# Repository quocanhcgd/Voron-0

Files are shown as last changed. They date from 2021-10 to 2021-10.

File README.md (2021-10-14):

# Voron Zero

Image of Voron Zero

The official release of the Voron Zero 3d printer.  You can find the BOM in the configurator located at the [Voron Design]( http://vorondesign.com/voron0) website.

The current revision is V0.1.

## Highlights
- Compact and portable
- 120x120x120 build volume
- CoreXY
- Low mass direct drive extruder
- Enclosed chamber
- 24v DC bed simplifies electronics
- Klipper firmware

## Release History
### V0.1 (2021 April)

A majority of the printed parts have changed. The configurator will give you an idea of parts needed if you are upgrading from V0.0.

**Toolhead**
- New design: Mini Afterburner
- Direct Drive Extruder with BMG gears and pancake motor with 10 tooth spur gear
- Improved part cooling ducts (fans are same as V0.0)
- Supports Mosquitto, Dragon, Dragonfly mounts
- V6 mount too large for DDE (bowden still an option)

**Z motor**
- Simplified to use Nema17 integrated T8x8 200mm leadscrew and printed mount (highly recommended upgrade)

**Drive units**
- A/B steppers changed to larger 40Ncm motors for increased torque (optional upgrade)
- Parts are now embossed with “A” or “B” respectively to avoid improper assembly
- Motor screws are countersunk to add more thread engagement 
- Panel mount point added

**Frame**
- No changes

**Electronics**
- Move from AC to 24v 60 watt DC bed (no more SSR)
- 150 watt PSU (larger to support DC bed)
- Fused AC power inlet (now with switch)
- SKR moves to rear compartment and Mini E3 V2.0 now spec
- PSU terminal cover

**Tophat**
- All panels have changed
- Front and rear are now straight vertical to accommodate new toolhead
- Sides went from 15° to 10°
- 10mm taller all around
- Lower panel clips are built into frame mounts

**Panels/clips**
- Front deck panel is unchanged
- Mid and back panel has various holes removed (can use your V0.0 panels)
- Rear deck panel is gone
- Motor panel is added (can be printed later)
- Side windows and door are unchanged
- Rear upper panel clips have an added mount point

**X/Y Joints**
- Hex nuts replaced with threaded inserts
- Idlers replaced by F623 bearing stack (hole adjusted to align perfectly in CAD)
- Endstop block changed to be compatible with DD toolhead
- Inaccessible bottom gantry screw holes removed

**Bed Assembly**
- Rear mounts extended 3mm to account for DD toolhead position changes
- Z chain mount adjusted to accommodate off-the-shelf chain or printed beltchain
- Zip tie mounts added for cable routing
- Removed horizontal bolt hole to prevent over-constraining assembly 
- Front mount reduced in size for less plastic use
- Printed thumb screws for bed adjustments

**Feet/Skirts**
- Extended to accommodate 34mm Z motor

**Front Idlers**
- No changes

### V0.0 Updates and fixes (2020 Sept)
See https://github.com/VoronDesign/Voron-0/releases/tag/V0.0r1

### V0.0 Initial release (2020 April)
See https://github.com/VoronDesign/Voron-0/releases/tag/V0.0

Voron Logo

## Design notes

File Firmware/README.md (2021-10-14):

# Voron 0.1 Stock Printer Config Example

For detailed instructions on setting up your Voron, visit
https://docs.vorondesign.com/build/startup/

As always, check Discord #voron_0_questions for help

## Quick Start
* Find and update your unique mcu `serial`
* Do a `STEPPER_BUZZ STEPPER=stepper_x` and repeat for each stepper
* Test each endstop using `QUERY_ENDSTOPS`
* Be ready to emergency stop, practice it
* Try homeing each axis, `G28 X` then `G28 X Y` then `G28`
* Adjust direction `dir_pin` as necessary
* Do a `BED_SCREWS_ADJUST` with the paper test
* Check fans are working properly
* Validate your thermistors `sensor_type`
* Tune bed `PID_CALIBRATE HEATER=heater_bed TARGET=100`
* Tune hotend with `M106 S64` then `PID_CALIBRATE HEATER=extruder TARGET=245`

## Warnings
* If using mainsail or others, you will likely need a special include or other adjustments
* You may need to swap your A/B motor physical connections and/or software stepper directions
* This firmware assumes stock BOM with Mini Afterburner DD toolhead

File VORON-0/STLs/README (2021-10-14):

STL's for RC1 release of VORON Zero

Files that are Prefixed with [a]_ are intended to be printed in the accent color all other files are intended to be printed in the base color

toolhead folders contain all the parts that need to be printed for each specific toolhead, print the parts that match the hotend you are using.

Panel mounting clips are offered in 3 sizes. print the sizes that matches the thickness of the panels you are using.

The TopHat is available in a unibody one piece design as well as a 4 piece design (for printing directly on the V0) choose one or the other, 
you do not need both. the mounting brackets for tophat panels are also offered in 3 sizes. print the sizes that matches the thickness of the panels you are using.

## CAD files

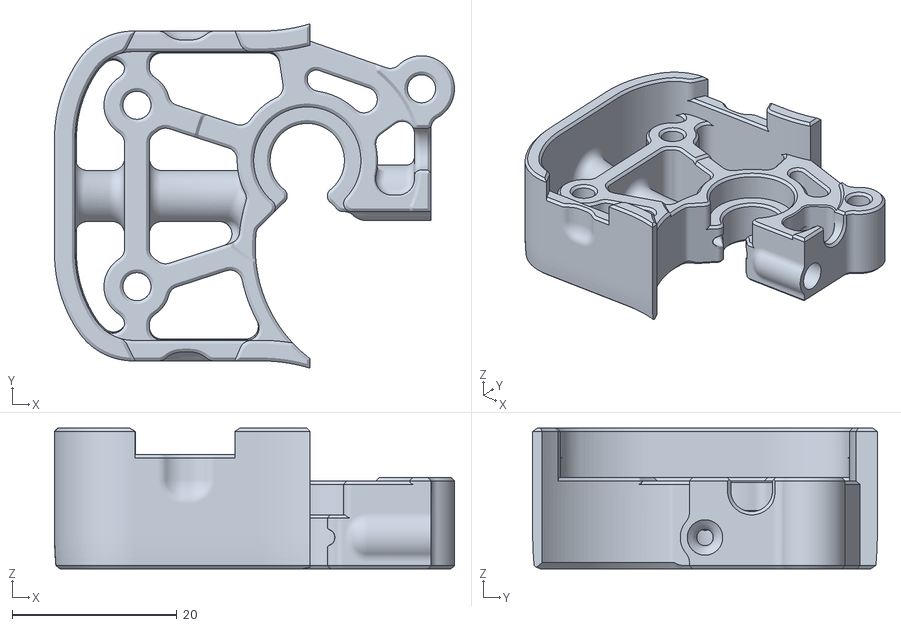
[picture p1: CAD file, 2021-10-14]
STLs/Toolheads/Mini_Afterburner/Dragon_Toolhead_DD/[a]_Mid_Body_Dragon_x1.stl
48.5 x 41.8 x 17.0

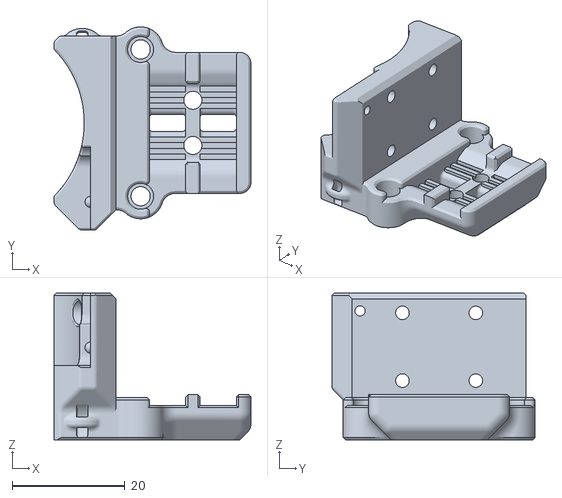
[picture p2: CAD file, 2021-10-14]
STLs/Toolheads/Mini_Afterburner/X_Carriage_90_x1.STL
34.9 x 36.0 x 26.0

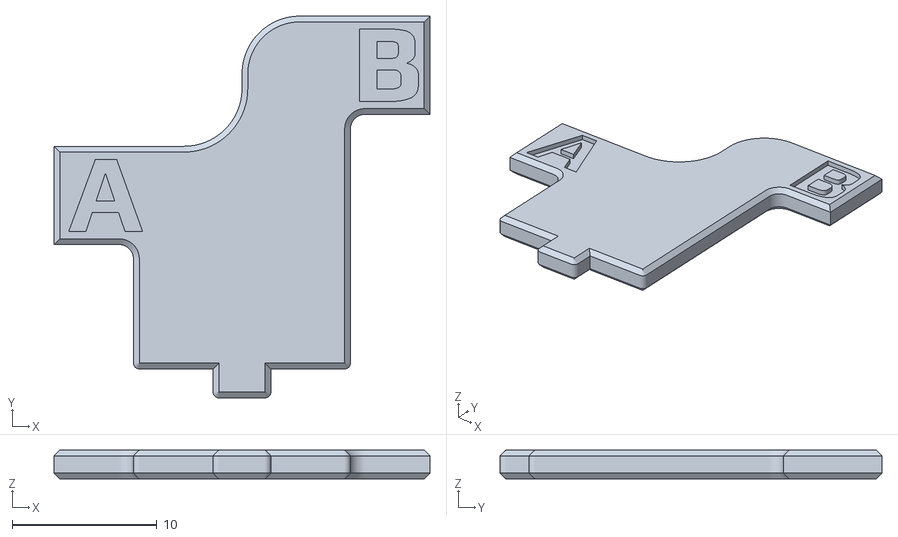
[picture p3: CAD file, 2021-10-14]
STLs/Tools/AB_pulley_jig_x1.stl
26.0 x 26.4 x 2.00

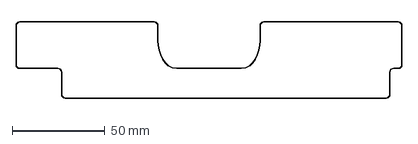
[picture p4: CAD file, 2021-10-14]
VORON-0/DXFs/Deck_Panel_Rear_V0.DXF
208.0 x 41.0 mm

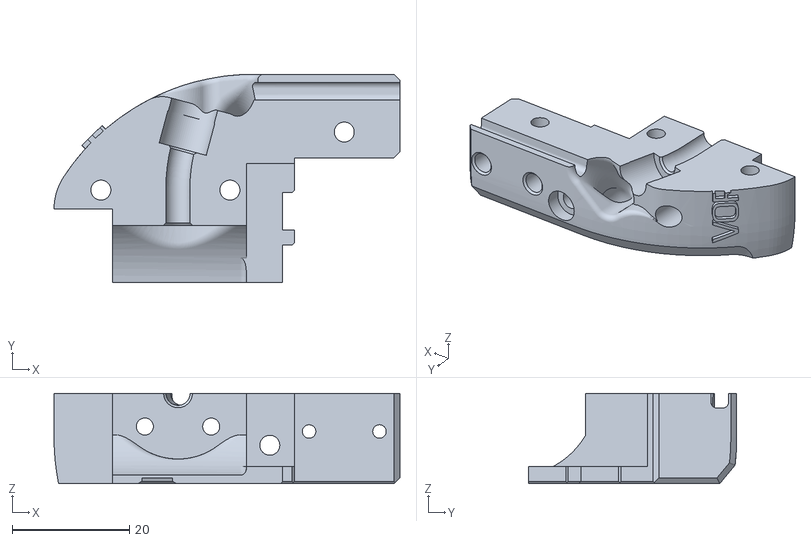
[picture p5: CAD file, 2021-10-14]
VORON-0/STLs/Dragon_Toolhead/Toolhead_Left_Dragon_x1.STL
59.0 x 35.6 x 15.4

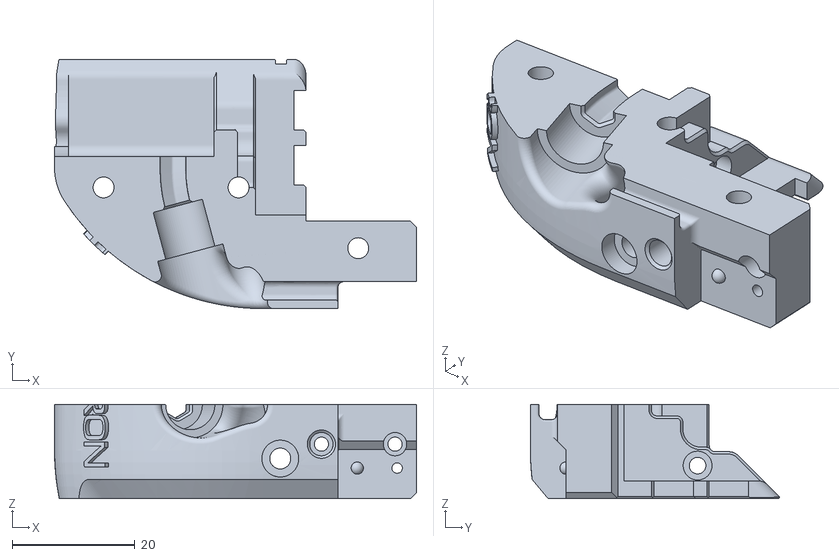
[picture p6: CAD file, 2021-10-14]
VORON-0/STLs/Mosquito_Toolhead/Toolhead_Right_Mosquito_x1.STL
59.0 x 40.6 x 15.4

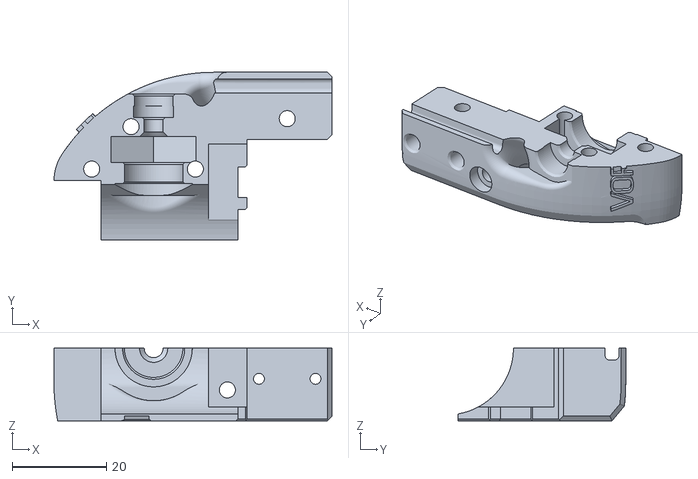
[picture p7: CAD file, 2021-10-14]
VORON-0/STLs/Threaded_V6_Toolhead/Toolhead_Left_Threaded_V6_x1.STL
59.0 x 35.6 x 15.4

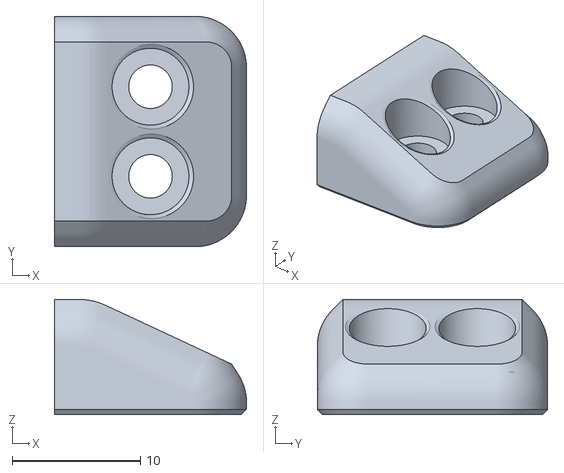
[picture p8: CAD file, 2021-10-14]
VORON-0/STLs/V0_Panel_Mounting/Door_Latch_x2.STL
15.0 x 18.0 x 9.00

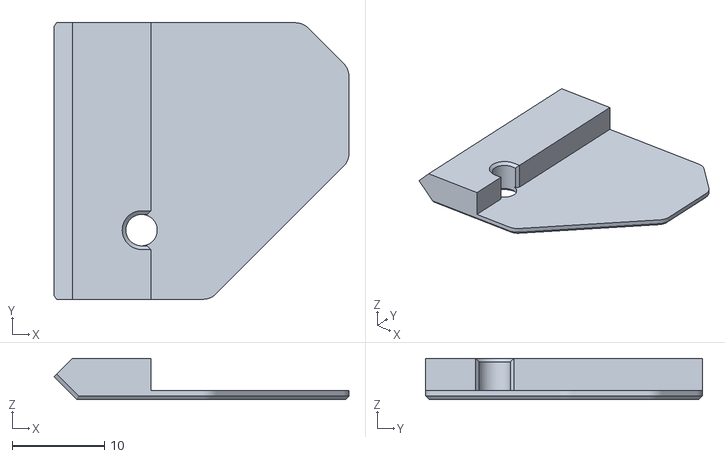
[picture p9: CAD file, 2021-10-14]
VORON-0/STLs/V0_Panel_Mounting/For_2.5mm_Panels/2point5mm_Bottom_Corner_Rear_x1.STL
32.0 x 30.0 x 4.50

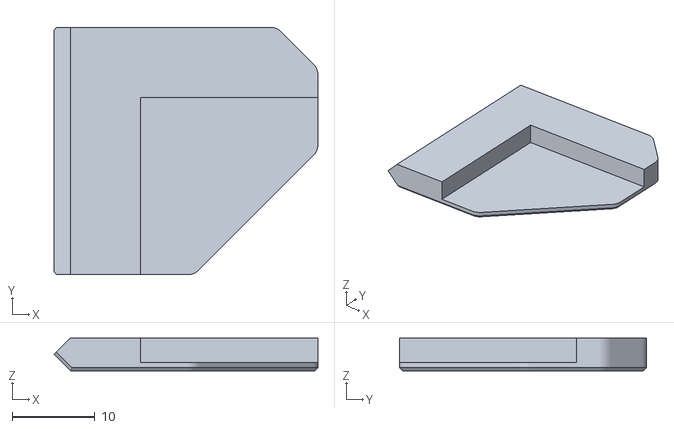
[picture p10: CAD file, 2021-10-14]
VORON-0/STLs/V0_Panel_Mounting/For_2mm_Panels/2mm_Bottom_Corner_Front_x1.STL
32.0 x 30.0 x 4.00

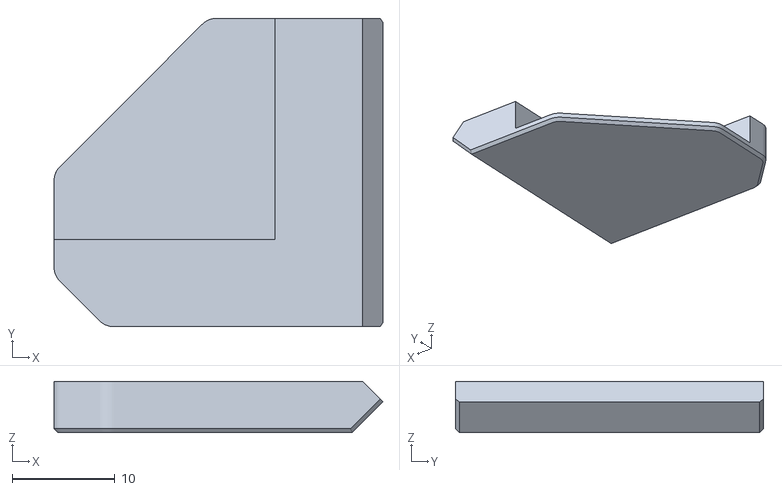
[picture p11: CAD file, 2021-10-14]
VORON-0/STLs/V0_Panel_Mounting/For_3mm_Panels/3mm_Bottom_Corner_Front_x1.stl
32.0 x 30.0 x 5.00

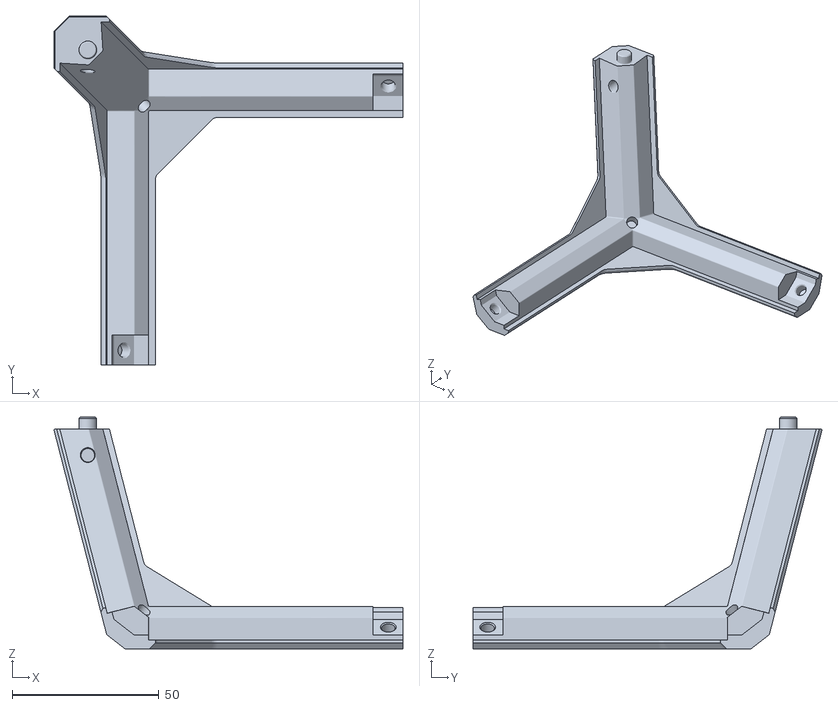
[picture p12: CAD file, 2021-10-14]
VORON-0/STLs/V0_TopHat/4_Piece_Tophat/TopHat_Right_x2.STL
119.0 x 119.0 x 79.0

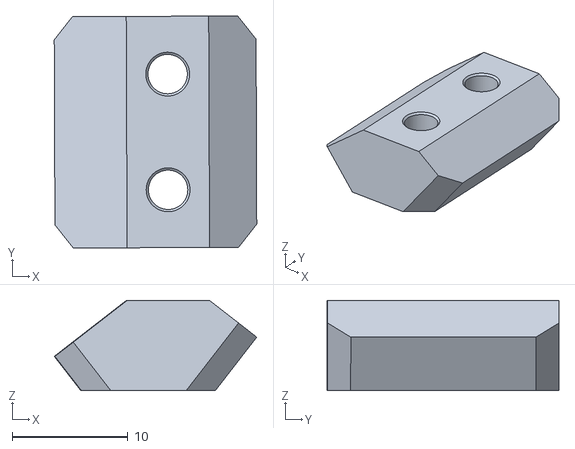
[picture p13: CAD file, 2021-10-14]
VORON-0/STLs/V0_TopHat/TopHat_Panel_Mounting/For_2.5mm_Panels/2point5mm_TH_Mid_Clip_x4.STL
17.5 x 20.1 x 7.78

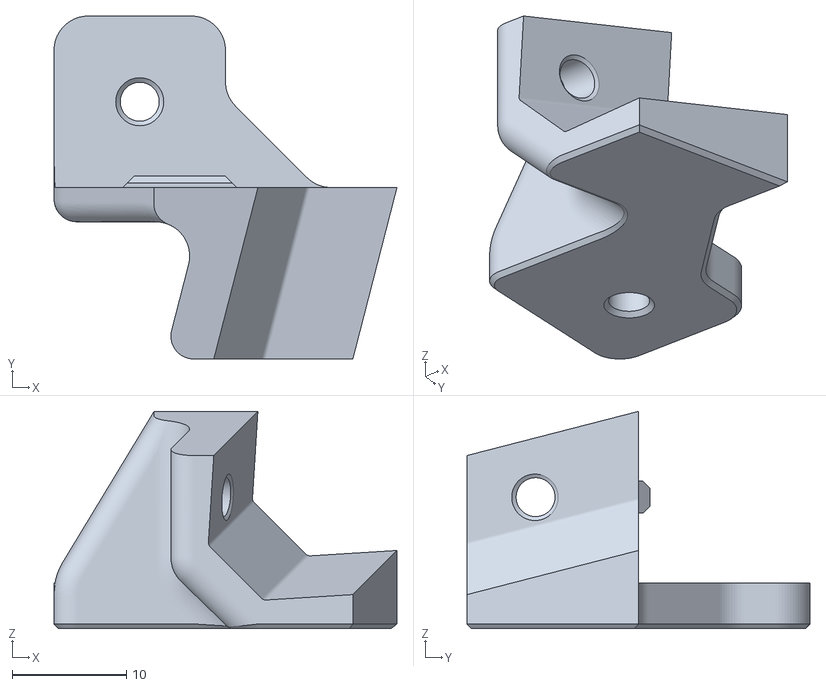
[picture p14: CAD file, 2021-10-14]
VORON-0/STLs/V0_TopHat/TopHat_Panel_Mounting/For_2mm_Panels/2mm_TH_Lower_Corner_Clip_Right_x2.stl
30.0 x 30.0 x 19.0

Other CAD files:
VORON-0/STLs/V0_TopHat/TopHat_Panel_Mounting/For_3mm_Panels/3mm_TH_Lower_Corner_Clip_Right_x2.stl
VORON-0/STLs/V0_TopHat/Unibody_Tophat/Unibody_Tophat_x1.STL
VORON_Pocketwatch/STLs/[a]_Mount_Bracket_x1.STL
VORON-0/DXFs/Back_Panel_V0.DXF
VORON-0/DXFs/Deck_Panel_V0.DXF
VORON-0/DXFs/Mid_Panel_V0.DXF
VORON-0/DXFs/TopHat_Side_Panel.DXF
VORON-0/STLs/A_Drive_Frame_Bottom_x1.STL
VORON-0/STLs/A_Drive_Frame_Top_x1.STL
VORON-0/STLs/A_Idler_Bottom_x1.STL
VORON-0/STLs/A_Idler_Top_x1.STL
VORON-0/STLs/B_Drive_Frame_Bottom_x1.STL
VORON-0/STLs/B_Drive_Frame_Top_x1.STL
VORON-0/STLs/B_Idler_Bottom_x1.STL
VORON-0/STLs/B_Idler_Top_x1.STL
VORON-0/STLs/Dragon_Toolhead/Toolhead_Right_Dragon_x1.STL
VORON-0/STLs/Front_Bed_Mount_x1.STL
VORON-0/STLs/M2_Nut_Adapter_Rotated_x5.stl
VORON-0/STLs/MGN7_Rail_Guide_x2.STL
VORON-0/STLs/RPi_Frame_x1.stl
VORON-0/STLs/Skirt_mirror_x3.STL
VORON-0/STLs/Skirt_x3.STL
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

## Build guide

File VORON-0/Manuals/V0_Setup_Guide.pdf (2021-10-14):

# Voron Design SKR Mini E3 Setup Guide

V0.0

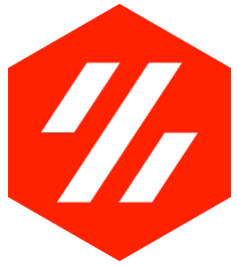
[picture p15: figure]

# Power Supply Wiring

## Safety Note

When wiring up your printer electronics, you will be working with high voltage wiring. Always double check to make sure that the printer is unplugged and any capacitors in your power supplies have discharged before touching any wire or terminal that may be live.

## Damage Risk

Never plug or unplug any device (high or low voltage) while the the printer is powered. In addition to being a safety hazard, you will likely damage electronic components. Of particular note are stepper drivers which can easily be damaged by connecting or disconnecting stepper motors or drivers while powered.

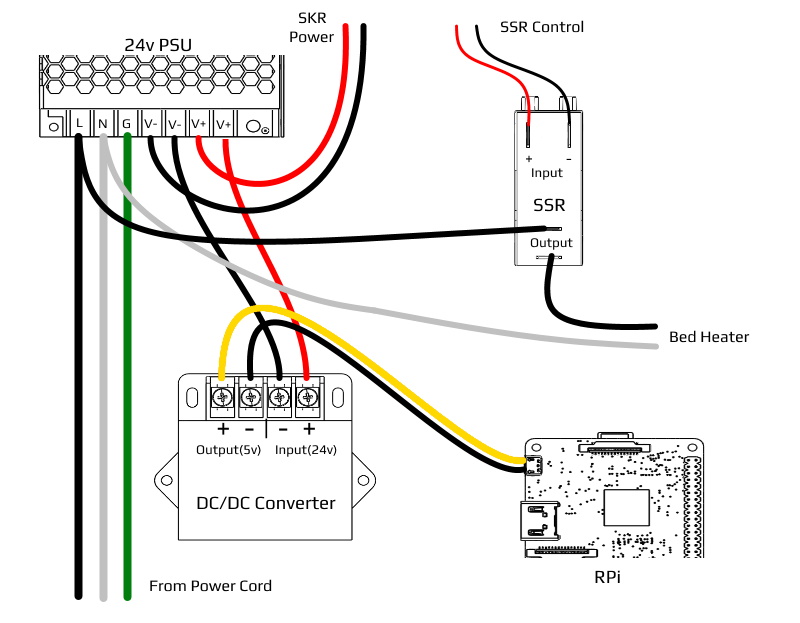
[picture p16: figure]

# SKR E3 Board Configuration

## Jumper Configuration

- Make sure power jumper is between INT and +5V (should be default from factory). If this is not installed correctly you may have power issues with your Raspberry Pi which can cause throttling

## Wire Terminals

SKR E3 boards use JST-XH terminals. This will mean that you will need to purchase a JST-XH connector kit with 2 pin, 3 pin, and 4 pin connectors. JST-XH terminals are keyed and will only fit in one orientation so pay close attention while crimping to make sure you do not make a mistake. You can carefully de-pin connectors with a dental pick, toothpick, or similar.

For wiring the stepper motors, keep the same wire color sequence that your stepper motors came with and make sure you use the same sequence for all of your stepper motors. If you have the spec motors from StepperOnline, the wires should in the the color order shown in the SKR E3 wiring diagrams on the following pages.

Note: Steppers should ship with a diagram that outlines wire pairs. You can also determine pairs by touching two wires together. If the stepper becomes more difficult to turn, then you have found a pair. These methods can be used if your wire colors are different or you mislabel wire order.

Important: If you find out your motors are going the wrong way once you start up your printer for the first time, you do not need to repin your connectors. You can invert the DIR (direction) pins in your configuration by adding or removing ! in front of pin and it will work properly.

## Endstop Wiring

There are two ways of wiring your endstops, one is NC (normally closed) and the other is NO (normally open). For normally closed configurations, the endstop switch allows current to flow through it when it is not triggered. For normally open configurations, the end stop switch only allows current to flow through it when it is triggered.

While both of these configurations will work fine in an ideal world, NC configurations are more robust because if a wire breaks or a terminal becomes disconnected, the printer will think that the end stop has triggered and the printer will stop movement before the toolhead crashes in to the frame or the bed.

Wiring mechanical end stop switches for NC operation is easy, as they generally have three pins exposed. With a multimeter, probe each combination of the three pins until you find a pair that has continuity (0 ohm resistance) when the switch is not triggered,

## MCU Wiring (X, Y, E, Hot End)

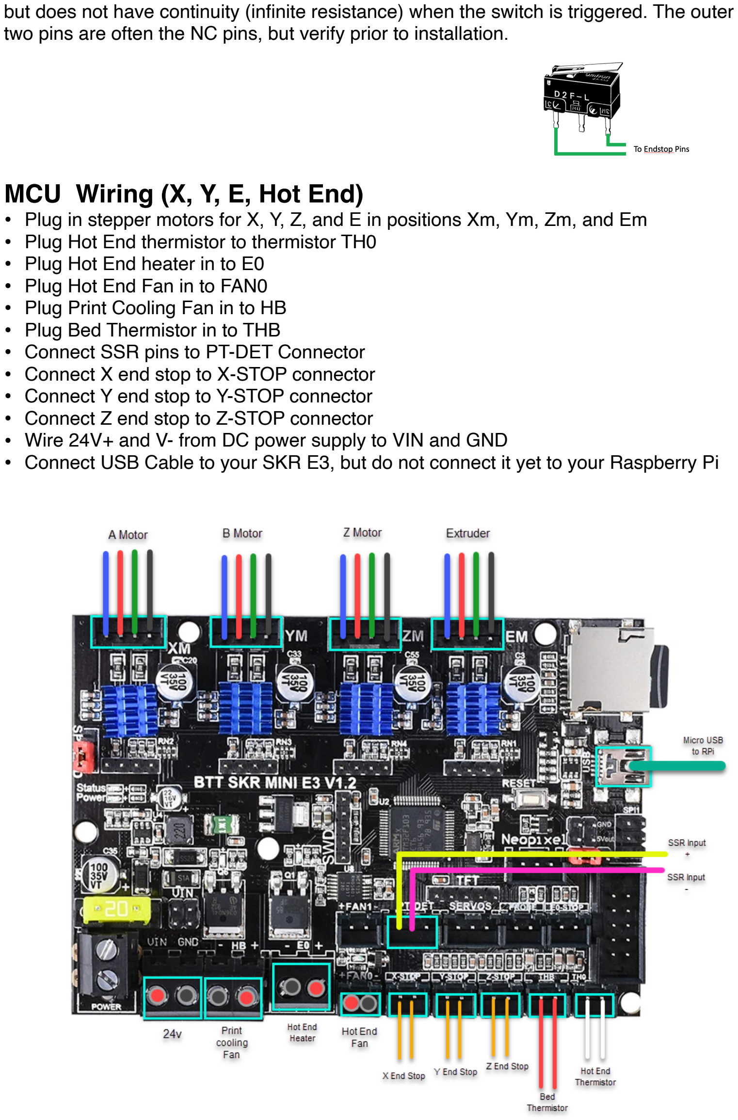
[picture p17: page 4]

but does not have continuity (infinite resistance) when the switch is triggered. The outer two pins are often the NC pins, but verify prior to installation.

- Plug in stepper motors for X, Y, Z, and E in positions Xm, Ym, Zm, and Em
- Plug Hot End thermistor to thermistor TH0
- Plug Hot End heater in to E0
- Plug Hot End Fan in to FAN0
- Plug Print Cooling Fan in to HB
- Plug Bed Thermistor in to THB
- Connect SSR pins to PT-DET Connector
- Connect X end stop to X-STOP connector
- Connect Y end stop to Y-STOP connector
- Connect Z end stop to Z-STOP connector
- Wire 24V+ and V- from DC power supply to VIN and GND
- Connect USB Cable to your SKR E3, but do not connect it yet to your Raspberry Pi

# Klipper Installation

References: Klipper Installation Instructions SKR Installation Instructions

## Installing Klipper Firmware on your SKR Mini E3 Board

- Install OctoPi on your Raspberry Pi (guide here: https://octoprint.org/download/)
- Once it is installed, ssh in to your Raspberry Pi using PuTTY on Windows or the Terminal on macOS

ssh pi@octopi OR ssh pi@192.168.1.X (Or whatever ip address your Raspberry Pi has)

- Enter password, the default one is “raspberry”. It is recommended to change this for security using
sudo raspi-config
Change the password via “Change User Password”
- Once you are at the command line of the Raspberry Pi, run the following commands: git clone https://github.com/KevinOConnor/klipper./klipper/scripts/install-octopi.sh
- When the install script has completed, run the following commands:
cd ~/klipper/
make menuconfig

In this menu structure, you’ll want to pick a few things. Make sure your Micro-controller Architecture is STM32, and your processor model is the STM32F103 with a 28KiB bootloader. Also select "enable extra low-level configuration options" and configure "GPIO pins to set at micro-controller startup" to "!PC13".
When your configuration matches the image below, select Exit and “Yes” if you are asked to save the configuration.

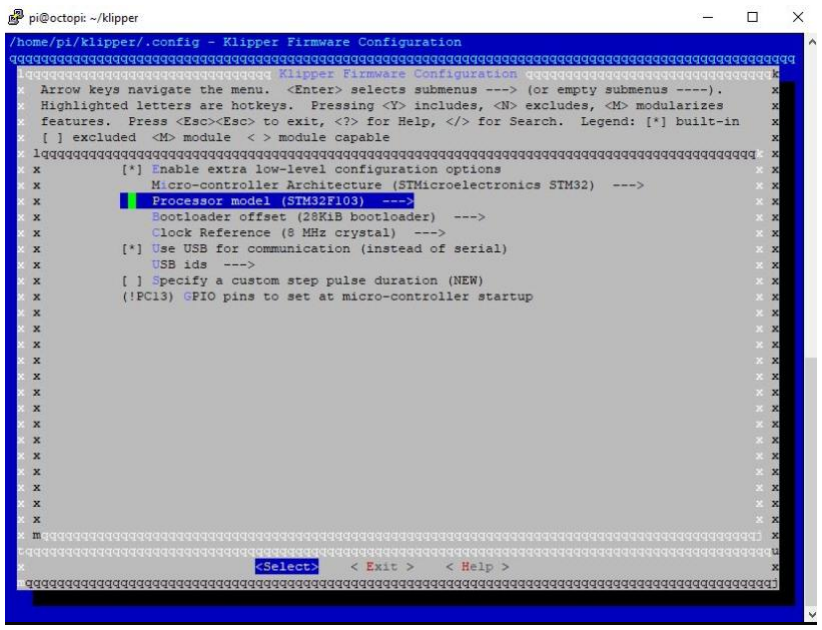
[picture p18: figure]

In the terminal window, type the following and pressing enter after each:

make clean

make

This command creates a firmware file klipper.bin that is stored in the folder /home/pi/ klipper/out.
The file needs to be copied to your Mini E3 board. The easiest way to do this is to use a program like WinSCP (Windows) or Cyberduck (Mac) to copy the file to your computer via SFTP. See the image on the next page that shows SFTP via Cyberduck.
- Copy the klipper.bin file to your desktop, and rename the file firmware.bin

Make sure the SKR Mini E3 is not powered, and then remove the microSD card.

- Connect the microSD card to your computer and open it.

There will be a file named firmware.cur on it—you can delete that file or keep it there, it does not matter.

- Copy the firmware.bin file from your desktop to the microSD card. If you have trouble transferring files from your computer to the microSD card, reformat the microSD card with a FAT32 file system and then try again.
- Plug the microSD cards back in to your SKR E3 board
- Turn on your power supply to power up your SKR E3 boards

Important: If you do not power your SKR with 12-24V, Klipper will be unable to communicate with the TMC drivers via UART and it will automatically shut down.

## Configuring Octoprint to use Klipper

Reference: KevinOConnor - klipper/docs/Installation.md
The OctoPrint web server needs to be configured to communicate with the Klipper host software.

Using a web browser, login to the OctoPrint web page and then configure the following items:

- Navigate to the Settings tab (the wrench icon at the top of the page)
- Under "Serial Connection" in "Additional serial ports" add "/tmp/printer" then click "Save"
- Open Settings tab and under "Serial Connection" change the "Serial Port" setting to "/ tmp/printer"
- In the Settings tab, navigate to the "Behavior" sub-tab and select the "Cancel any ongoing prints but stay connected to the printer" option, then click “Save”
- From the main page, under the "Connection" section (at the top left of the page) make sure the "Serial Port" is set to "/tmp/printer" and click "Connect". (If "/tmp/ printer" is not an available selection then try reloading the page)
- Once connected, navigate to the "Terminal" tab and type "status" (without the quotes) into the command entry box and click "Send". The terminal window will likely report there is an error opening the config file - that means OctoPrint is successfully communicating with Klipper.

## Setting up Voron Printer Configuration File

- Download the Voron Zero configuration file from the VORON 0 Github
- Transfer the downloaded file to your raspberry pi in the following folder: ~/home/pi

Note: There are many ways of editing your config file. Using the built-in Nano editor through SSH is simple, but it is not user friendly. Notepad++ with the NppFTP plugin (Windows) or bbEdit (MacOS) are better alternatives. Instructions on how to use them are in the appendix.

- Review the configuration file by typing:
nano ~/printer.cfg

You’ll notice that near the top of the file, there is a section titled [mcu] this section is where we define that we will be using the SKR E3 controller, and identifying the controller so that Klipper knows that components are connected to it. First of all, we need to identify what the Raspberry Pi calls the controller so we can correctly list it in the configuration.

- Take the USB cable from the SKR E3 and plug this in to one of the USB ports on your Raspberry Pi, then run the following command:
ls -l /dev/serial/by-id/

You should see something similar to this:

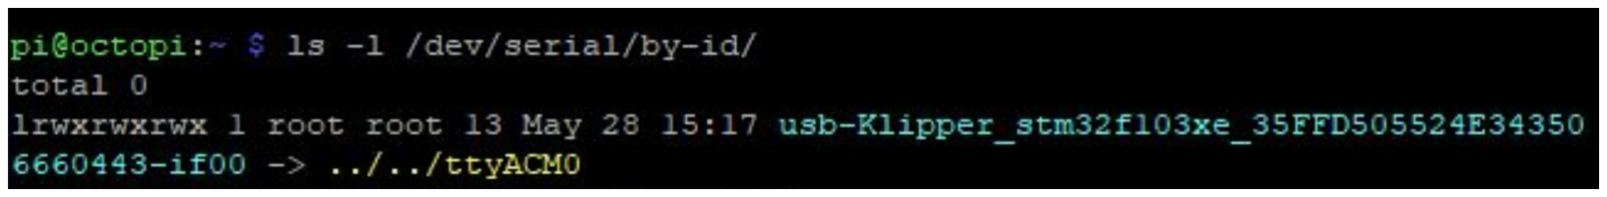
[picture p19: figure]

- Copy the corresponding text from your terminal window usb-Klipper_stm32f103xe_35FFD3054E4B323825611343-if00 and paste it in a text file temporarily.
- Open your configuration file (nano ~/printer.cfg) and navigate to the [mcu] section. After the text “serial: /dev/serial/by-id/” paste your SKR path so that the line becomes:

serial: /dev/serial/by-id/usb-Klipper_stm32f103xe_35FFD3054E4B323825611343-if00

- this wont be the exact line, your ID number will be different but the formate should be similar
- Exit the text editor using CNTL-X, and save when asked.
- Under Octoprint’s Terminal tab type:
FIRMWARE_RESTART and press enter send the command to restart Klipper.

NOTE: Pay close attention and complete the remaining configuration checks. If you do not complete these steps, your printer will not run!
1. Under [extruder] verify that your sensor_type is correct. Do not worry about step_distance and pid values for now, they will be updated later in the setup process.
2. Under [heater_bed], verify that your sensor type is correct.

Save the configuration file.

- Under Octoprint’s Terminal tab type:
FIRMWARE_RESTART and press enter send the command to restart Klipper.

The terminal window should show a status “Ready”—if not, type “status” in to the terminal command and press enter. If Klipper says that it is not ready, it will generally notify you if there is a configuration issue that needs to be fixed.

## Common Klipper Errors

TMC UART Error: This appears when the communication between the TMC drivers and the SKR is not working. Typically this means that you have not powered the SKR board with 12-24V (TMC drivers didn’t boot), you haven’t plugged in the TMC steppers to the correct spots, or you forgot to add or remove a jumper as detailed above.

ADC Error: ADC stands for “Analog to Digital Converter” and is what is used to convert thermistor readings to temperatures for your hotend and heated bed. As a safety precaution, if Klipper is expecting a thermistor to be plugged in but it is reading an invalid reading (no thermistor = open, or 0 ohms for a shorted wire as closed), it will go in to this shut down mode.

Unable to connect: Once the underlying issue is corrected, use the "FIRMWARE_RESTART" command to reset the firmware, reload the config, and restart the host software.
Check MCU IDs match your printer.cfg
"Make sure you get the paths right”

## Klipper Troubleshooting

Retrieve Log File: The Klippy log file (/tmp/klippy.log) contains debugging information. M112 command in the OctoPrint terminal window immediately after the undesirable event

There is a logextract.py script that may be useful when analyzing a micro-controller shutdown or similar problem.
mkdir work_directory

cd work_directory
cp /tmp/klippy.log .
~/klipper/scripts/logextract.py ./klippy.log
The script will extract the printer config file and MCU shutdown information to work_directory.

# Klipper Configuration Checks

The moment you’ve been waiting for—your printer finally coming to life! Klipper has a very helpful configuration check guide that will help make sure that everything is operating properly. Please follow the steps detailed at the URL below:

https://github.com/KevinOConnor/klipper/blob/master/docs/Config_checks.md

## Endstop Check

Make sure that none of the X, Y, or Z Endstops are being pressed, and then send a QUERY_ENDSTOPS command via the Octoprint command line. The terminal window should respond with the following:

Send: QUERY_ENDSTOPS
Recv: x:open y:open z:open

If any of them say “triggered” instead of “open”, double check to make sure none of them are pressed. Next, manually press the X endstop, send the QUERY_ENDSTOPS command again, and make sure that the X endstop says “triggered” and the Y and Z endstops stay open. Repeat with the Y and Z endstops.

You may find that one of your Endstops has inverted logic (it displays “open” when it is pressed, and “triggered” when it is not). In this case, go to your printer’s config file and add or remove the ! In front of the pin. For instance, if your X endstop was inverted, you would add a ! In front of your pin number as follows:

endstop_pin: P1.28 —> !P1.28

## Stepper Motor Check

To verify that each stepper motor is operating correctly, send the following command: STEPPER_BUZZ STEPPER=stepper_x
Run this again for each of the motors (stepper_y, stepper_z, extruder). the Z motor should go UP first then down by 1mm each direction. If the stepper motors do not move, check wiring for loose connectors. if the steppers move the wrong direction flip the connector on your board.

## XY Homing Check

It’s time to start by homing X and Y! You’ll want to be able to quickly stop your printer in case something goes wrong (ie, the tool head goes in the wrong direction). There are a few ways of doing this—one is to use the E-stop button on your display (if you have one installed). Test the button and see what happens—Klipper should shut down, but the Raspberry Pi and Octoprint will still be running, but disconnected from Klipper. Press “Connect” in the upper left corner of Klipper, and then in the Octoprint terminal window send a FIRMWARE_RESTART command to get your printer back up and running.

The alternative to this is to have your laptop right next to the printer with “restart” already in the terminal command line in Octoprint. When you start homing your printer, if it goes in the wrong direction—quickly send the restart command and it will stop the printer.

The final option is to power off the entire printer if something goes wrong.

Now that you know how to stop the printer if something goes wrong, send a G28 X Y command to your printer. This will only home X and Y, not Z. The tool head should move to the right until it hits the X endstop, and then move to the back of the printer until it hits the Y endstop. In a CoreXY configuration, each motor has to move in order to get the toolhead to go in only an X or Y direction (think of an Etch a Sketch).

If the toolhead does not go in the correct direction, refer to the table below to figure out how to correct it. If you need to invert one of the motors, invert the direction pin (put a ! before the pin). If the motors are going in the directions that match the lower row, swap your X and Y connectors.

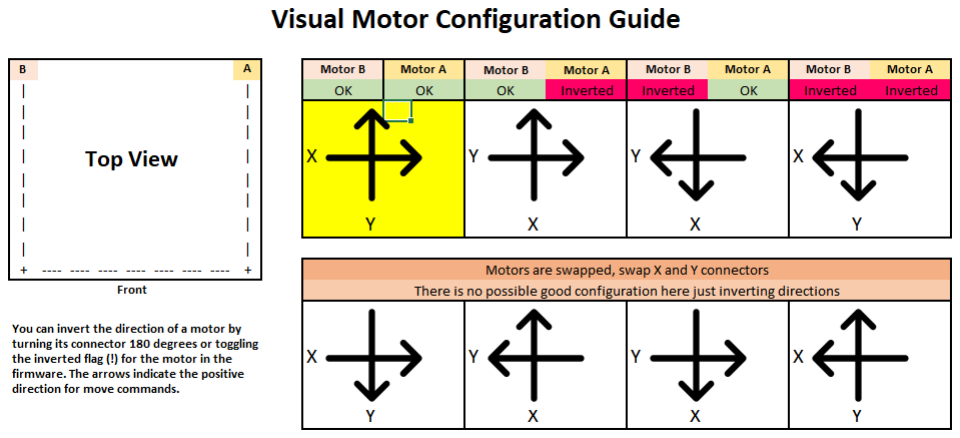
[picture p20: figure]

[stepper x] => Motor B
[stepper y] => Motor A

## Define (0,0) Point

Home XY
Move the nozzle to the front left corner of the bed. Once you can get the nozzle close to the front left corner of the bed, send an M114 command. If X and Y are not ~0-5mm, update “position_max” and “position_endstop” for both [stepper_x] and [stepper_y]: For X: New = Current – Get Position X Result

For Y: New = Current – Get Position Y Result
If you update anything in your configuration file, save the file and then restart Klipper using FIRMWARE_RESTART.

## PID Tune Heated Bed

Move nozzle to the center of the bed and approximately 5-10mm above the bed surface, then run:

PID_CALIBRATE HEATER=heater_bed TARGET=100

It will perform a PID calibration routine that will last about 10 minutes. Once it is finished, type SAVE_CONFIG which will save the parameters into your configuration file.

## PID Tune Hotend

Set the part cooling fans to 25% (M106 S64) and then run:

PID_CALIBRATE HEATER=extruder TARGET=245

It will perform a PID calibration routine that will last about 5 minutes. Once it is finished, type SAVE_CONFIG which will save the parameters into your configuration file.

## Z Offset Adjustment

If you did not run PID tuning, set your extruder to 245C and heated bed to 100C and let the printer heat up for 15 minutes.

Run a G28, and then move the nozzle to the center of the bed

Run Z_ENDSTOP_CALIBRATE

Slowly move the nozzle toward the bed by using
TESTZ Z=-1
Until the nozzle is relatively close to the bed, and then stepping down with
TESTZ Z=-0.1
Until the nozzle touches a piece of paper on top of the build plate. If you go far down, you can move the nozzle back up with:
TESTZ Z=0.1
Once you are satisfied with the nozzle height, type “ACCEPT” and then
“SAVE_CONFIG”.

If you get an error (out of bounds), send Z_ENDSTOP_CALIBRATE, ACCEPT, and then SAVE_CONFIG. This will redefine the 0 bed height so you will be able to get closer.

you will need to re-run these Z offset adjustment steps after the completion of the bed leveling section as well.

## Bed Leveling

The V0 uses manual bed leveling, the bed is small enough and thick enough that a mesh or other types of per print leveling are not needed. there is a Macro in Klipper to help with the manual bed leveling process

BED_SCREWS_ADJUST

This tool will move the printer's nozzle to each screw XY location and then move the nozzle to a Z=0.3 height. At this point one can use the "paper test" to adjust the bed screw directly under the nozzle. See the information described in "the paper test", but adjust the bed screw instead of commanding the nozzle to different heights. Adjust the bed screw until there is a small amount of friction when pushing the paper back and forth. this process will move all three mounting points of your bed closer to the nozzle so it is critical that you re-run the Z offset adjust after completing this section.

Once the screw is adjusted so that a small amount of friction is felt, run either the ACCEPT or ADJUSTED command. Use the ADJUSTED command if the bed screw needed an adjustment (typically anything more than about 1/8th of a turn of the screw). Use the ACCEPT command if no significant adjustment is necessary. Both commands will cause the tool to proceed to the next screw. (When an ADJUSTED command is used, the tool will schedule an additional cycle of bed screw adjustments; the tool completes successfully when all bed screws are verified to not require any significant adjustments.) One can use the ABORT command to exit the tool early.

After the BED_SCREWS_ADJUST command has been completed rerun the Z_ENDSTOP_CALIBRATE command to to bring your nozzle to the correct Z=0 position.

## Extruder Calibration

Before your first print, you need to make sure that your extruder extrudes the correct amount of material. With the hotend at temperature, make a mark between your roll of filament and your extruder, 120mm away from the entrance to your extruder. In Octoprint, extrude 50mm 2 times (for a total of 100mm—Klipper doesn’t allow you to extrude more than 50mm at a time), then measure from the entrance of your extruder to the mark you made previously. In a perfect world, it would measure 20mm (120mm -20mm = 100mm), but it usually won’t be. Take the value you have in your configuration file and update it using the following:

New Config Value = Old Config Value * (Actual Extruded Amount/Target Extruded Amount)

Note that a higher configuration value means that less filament is being extruded.

Paste the new value into your configuration file, restart Klipper, and try again. Once your extrusion amount is within 0.5% of the target value (ie, 99.5-100.5mm for a target 100mm of extruded filament), your extruder is calibrated!

## Fine Tuning Z Height

As a reference, if you adjust the Z offset during a print using the Tune menu on your display, you can update your printer configuration with this new value. Remember that higher values for your Z_endstop_position mean that the nozzle will be closer to the bed.

New Position = Old Position - Tune Adjustment
New Position = Old Position - (-0.050) = Old Position + 0.050

# Slicer Setup and First Print

## Cura Installation

For your first print, use the latest version of Cura, but do not open it at first. Download the latest Voron Cura setup files pinned in #slicers_and_print_help, and then extract the zip folder into C:\Program Files\Ultimaker Cura X.X\resources.

Once that is complete, open Cura and under “non-networked printer” find the Voron tab and select the size of your printer. All the settings should be pre-populated for you.

## First Print

Download the “voron_design_cube_v6.stl” from the Voron Github page (Voron-2/STLs/ TEST_PRINTS), and open the file in Cura. Use the default slicer settings, but make sure the hotend temperature and bed temperature is correct for the filament you are using. A good starting point is 240C hotend temperature, 100C heated bed temperature, and 92% flow for ABS.

Slice the file and save the .gcode file to your desktop (if you haven’t set up the Octoprint Plugin). Navigate to Octoprint in your web browser, and upload the file to Octoprint. Press “Print” and closely watch the beginning of the print. If your nozzle is too far or close to the bed, on your printer display press the knob, navigate to “Tune”, and adjust the Z offset distance (+ is further from the bed, - is closer).

Once you are printing (with your printer fully assembled), take a quick video, upload it to the Voron subreddit and eat a well deserved bowl of cereal!

# Appendix

## Appendix 1 - Notepad++ Configuration Editing (Windows)

1. Install Notepad++ from: https://notepad-plus-plus.org
2. Under the “Plugins” tab, select “Plugins Admin”
3. Search for “NppFTP”, select the check box, and click “Install”
4. Restart Notepad++ if necessary
5. On the right, there will be a new section. Click the gear icon and select “Profile Settings”
6. In the bottom left, select “Add New” and name the profile as you wish
7. In the Hostname dialog, enter the IP address of your Raspberry Pi
8. In Connection Type, select SFTP
9. Port: 22
10. Username: pi
11. Password: *** (default is raspberry)

12. Close the dialog box, select the blue symbol, and select the name of the profile you created
13. Notepad++ will connect to your Raspberry Pi and display the file structure
14. Navigate to /home/pi and open printer.cfg
15. Make any applicable edits and then save the file

Remember to restart klipper from the Octoprint terminal to see your changes take affect!

## Appendix 2 - bbEdit Configuration Editing (macOS)

1. Install bbEdit. The free version works great! https://www.barebones.com/products/bbedit/
2. Under File, select Open from FTP/SFTP Server…”
3. Under Server, type in your Raspberry Pi’s IP address (will be different)
4. Select SFTP
5. Enter “pi” as the user
6. Enter your password, it will be “raspberry” unless you changed it.
7. Select Continue
8. Find “printer.cfg” in the file browser and double click to open the file
9. Make any necessary edits and save the file

Remember to restart klipper from the Octoprint terminal to see your changes take affect!

## Appendix 3 - Recommended Octoprint Plugins

- OctoKlipper
- Themeify
- TerminalCommands
- Bed Level Visualizer
- Print Time Genius

## Appendix 5 - Other Accessories

To add LED lights inside the enclosure, wire up the (+) side of the LEDs to a power supply that matches the LED rated voltage, and the (-) side of the LEDs to one of the H-Bed (Heated Bed) connectors on either MCU. Define this output in your klipper configuration file and install an Octoprint plugin to control these LEDs.

## Appendix 6 - Contributors

- eddie V2.058
- nemgrea V2.199

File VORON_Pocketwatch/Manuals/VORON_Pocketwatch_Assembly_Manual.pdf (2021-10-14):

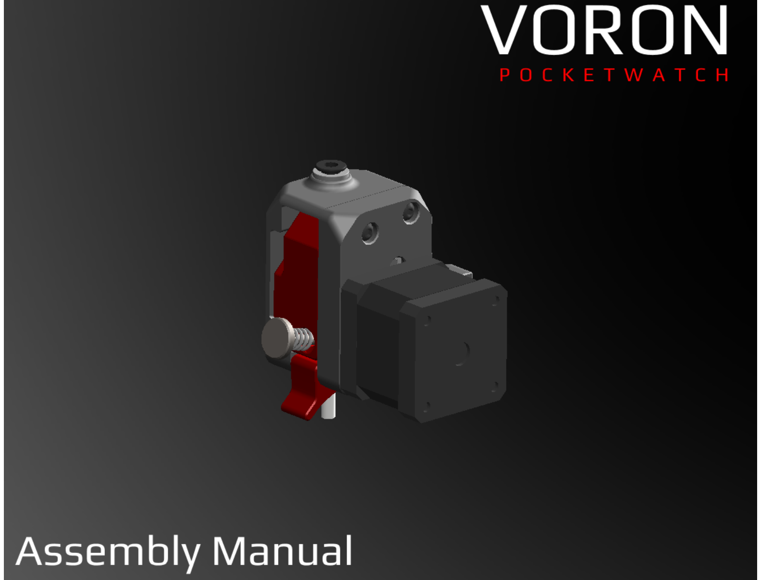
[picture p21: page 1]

# Please, read the entire manual before you start assembly. As you begin wrenching, please check our Discord channel (#voron_v0_questions) for any

tips and questions that may halt your progress.

# Most of all, good luck!

# - The VORON Development Team

## File Key / Part Printing Guidelines and Standards

## Part Printing Guidelines and Standards

Approved FDM Materials | ABS or ABS+ Only
Layer Height | 0.2mm
Extrusion Width | Forced 0.4mm
Infill Percentage | 40% minimum
Infill Type | Grid, Gyroid, Honeycomb, Triangle or Cubic
Wall Count | 4 minimum
Solid Top/Bottom Layers | 5 minimum

## File Key

Primary Color | nothing at start of file name
Accent Color | [a]_ at start of file name
Quantity Required | _x# near end of file name

# Very Important Steps

# Notes and Tips

# Fastener Size/Type Part

## Important Definitions and Adhesives List

Callout | Definition
BHCS | Button Head Cap Screw (ISO 7380-1)
SHCS | Socket Head Cap Screw (ISO 4762/DIN 912)
Shim | Shim Ring (DIN 988)
Nut | DIN934 or equivalent
Lock Nut | DIN985 or equivalent
Low Strength Thread Locker | Loctite 222 (aka “Purple”)
Shaft Retaining Compound | Loctite 641 ("Yellow") or 609 ("Light Green")

## Important Definitions and Adhesives List

## BMG Drive Gears

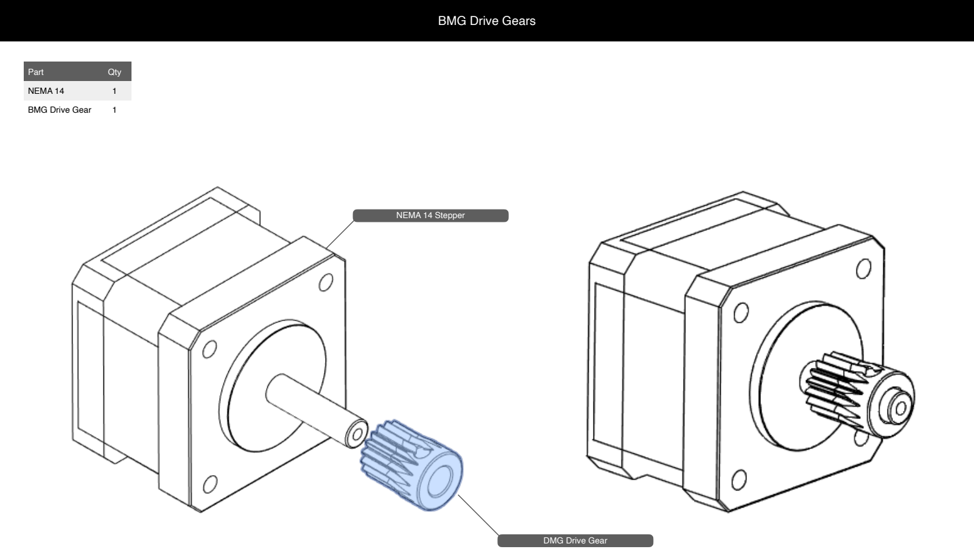
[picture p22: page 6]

Part | Qty
NEMA 14 | 1
BMG Drive Gear | 1

NEMA 14 Stepper

DMG Drive Gear

## BMG Drive Gears

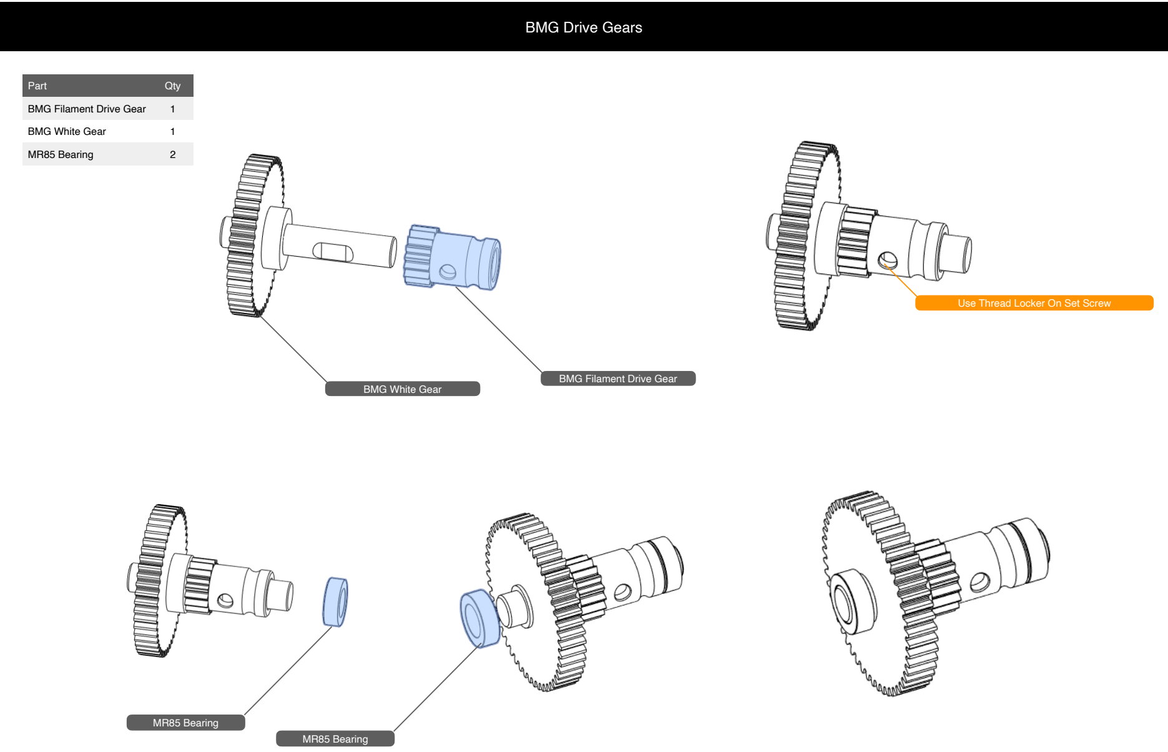
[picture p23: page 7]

BMG Filament Drive Gear
BMG White Gear

MR85 Bearing
MR85 Bearing
Part | Qty
BMG Filament Drive Gear | 1
BMG White Gear | 1
MR85 Bearing | 2

Use Thread Locker On Set Screw

## Motor Frame

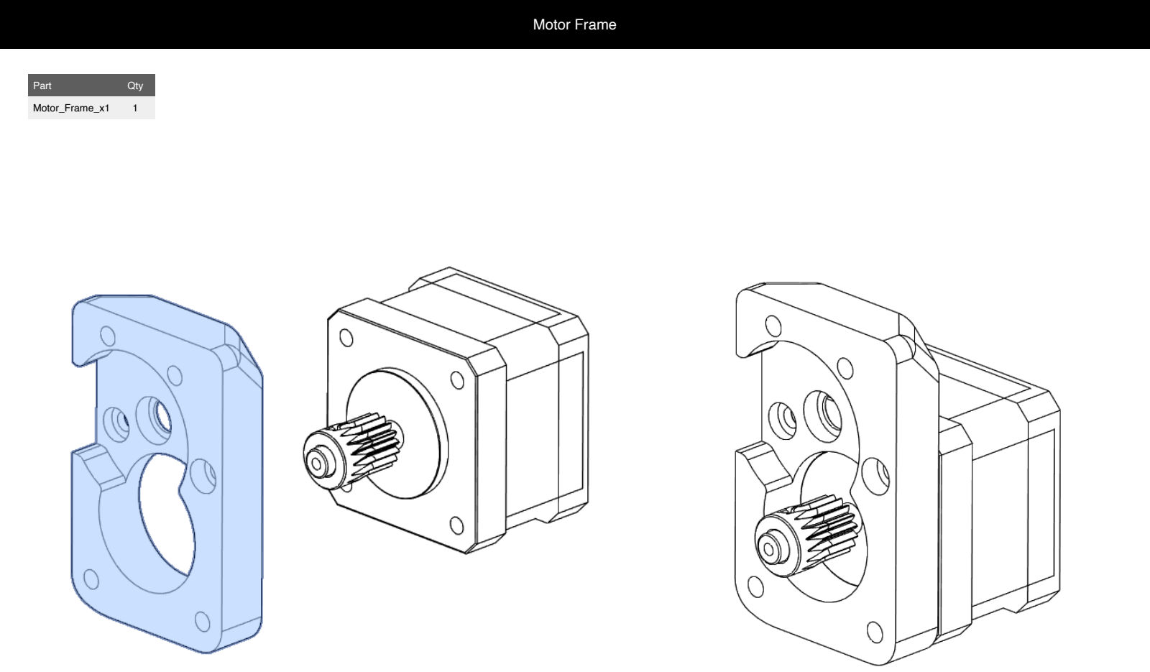
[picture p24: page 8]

Part | Qty
Motor_Frame_x1 | 1

## Motor Frame

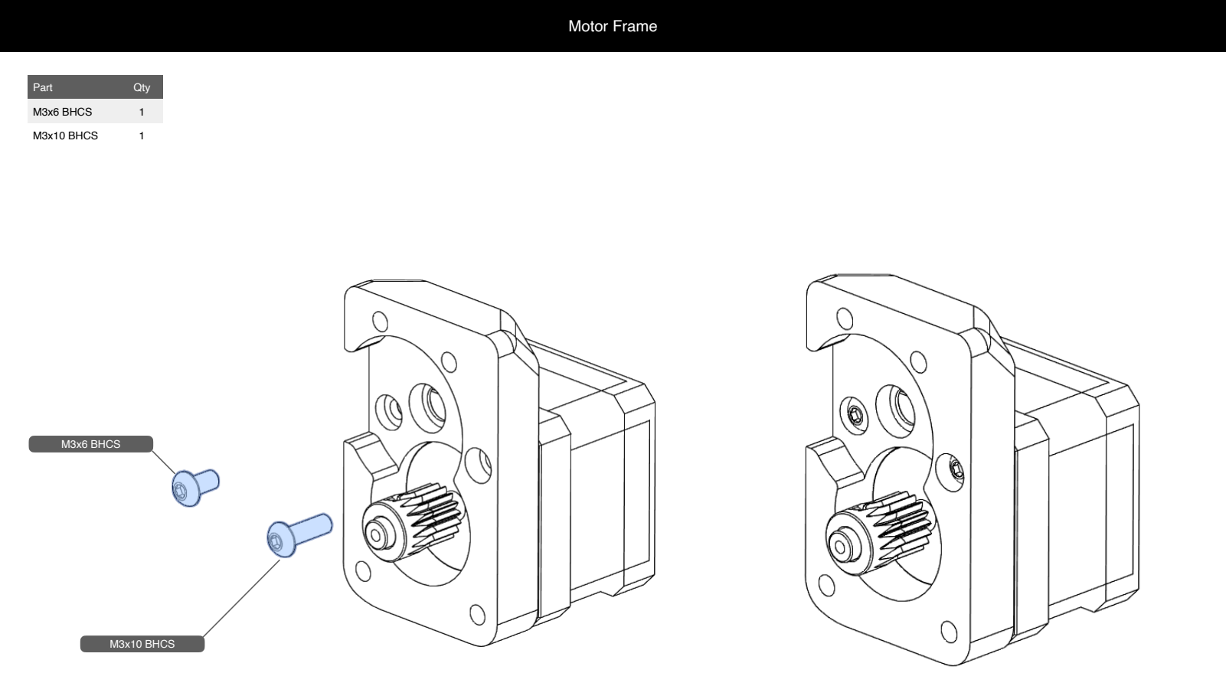
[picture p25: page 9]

M3x10 BHCS

M3x6 BHCS

Part | Qty
M3x6 BHCS | 1
M3x10 BHCS | 1

## BMG Drive Gears

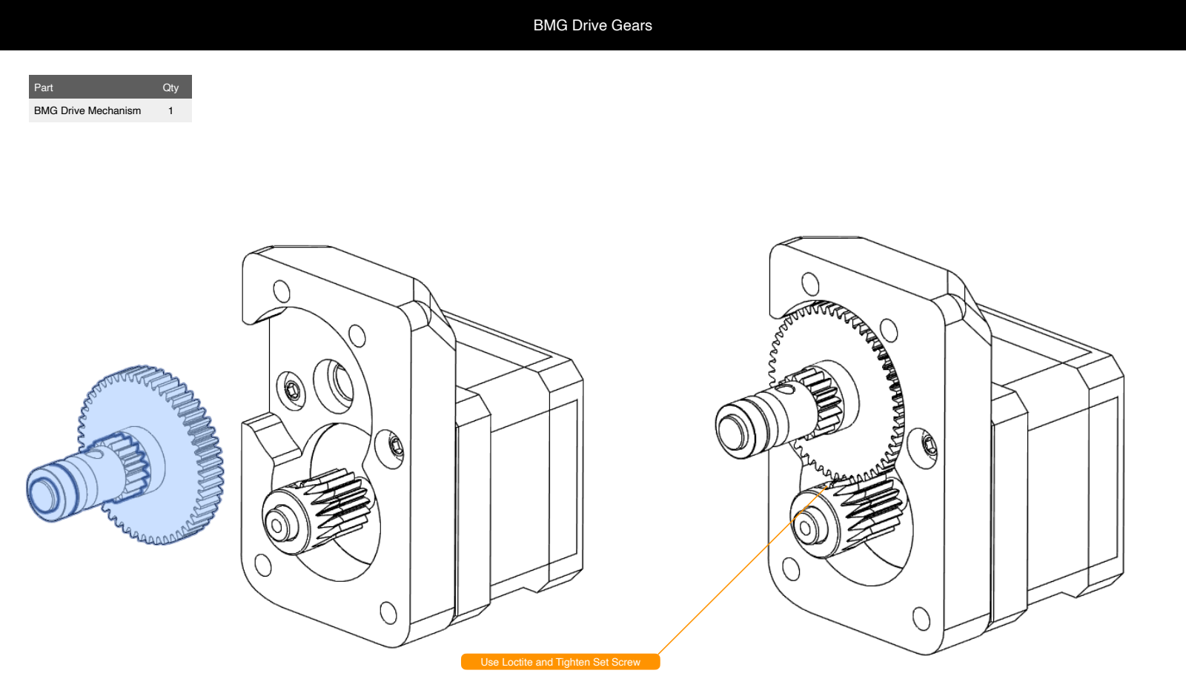
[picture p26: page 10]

Use Loctite and Tighten Set Screw

Part | Qty
BMG Drive Mechanism | 1

## Guidler Door Assembly

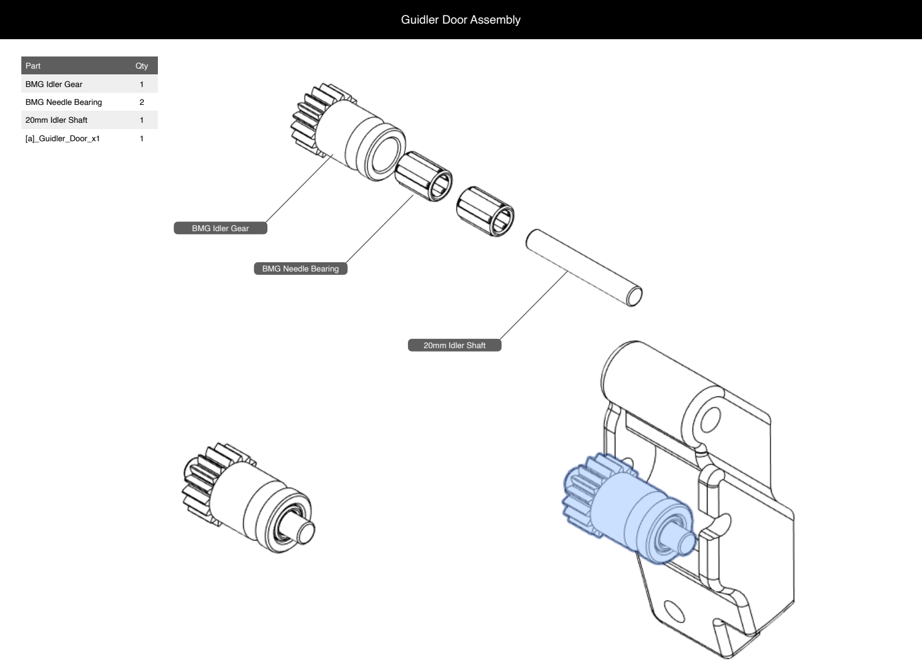
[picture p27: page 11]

BMG Idler Gear

BMG Needle Bearing

20mm Idler Shaft

Part | Qty
BMG Idler Gear | 1
BMG Needle Bearing | 2
20mm Idler Shaft | 1
[a]_Guidler_Door_x1 | 1

## Door Assembly

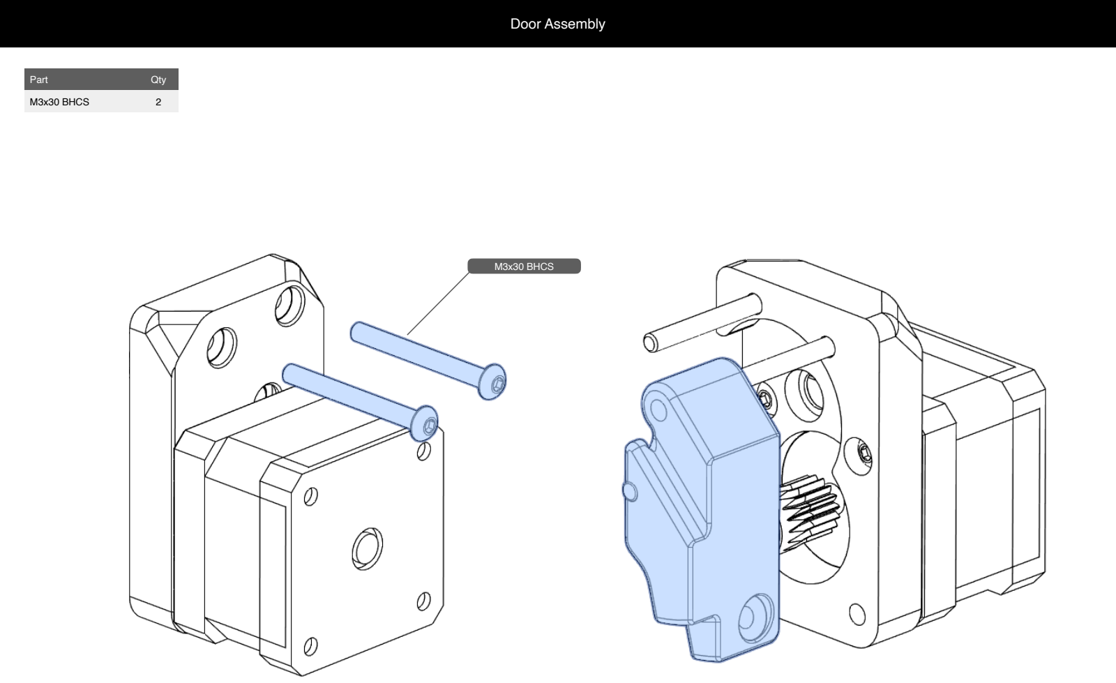
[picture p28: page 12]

M3x30 BHCS

Part | Qty
M3x30 BHCS | 2

## Motor Assembly

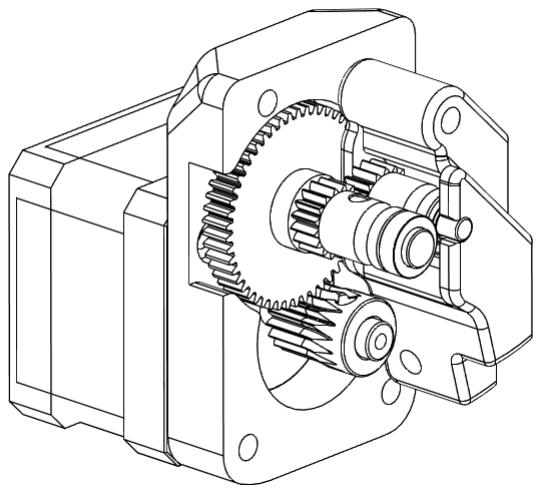
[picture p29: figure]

## Guts Assembly

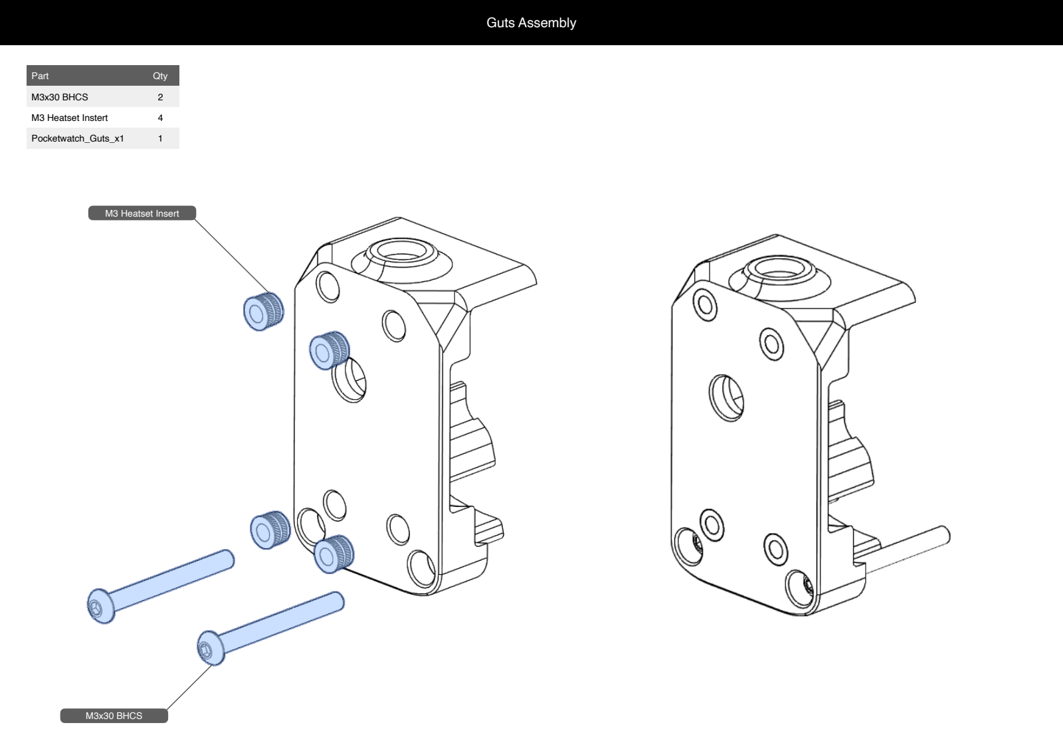
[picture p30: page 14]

M3x30 BHCS

M3 Heatset Insert

Part | Qty
M3x30 BHCS | 2
M3 Heatset Instert | 4
Pocketwatch_Guts_x1 | 1

## Heatset Insert

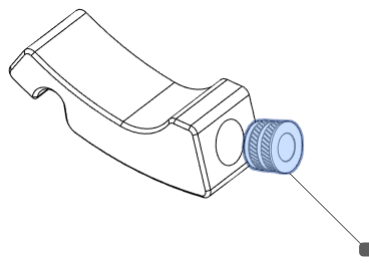
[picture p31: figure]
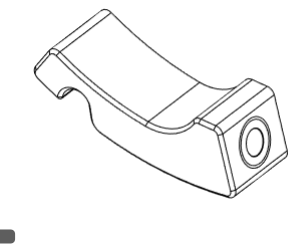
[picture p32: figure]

M3 Heatset Insert

Part | Qty
[a]_Latch_Shuttle_x1 | 1
M3 Heatset Insert | 1

## Install Latch Shuttle

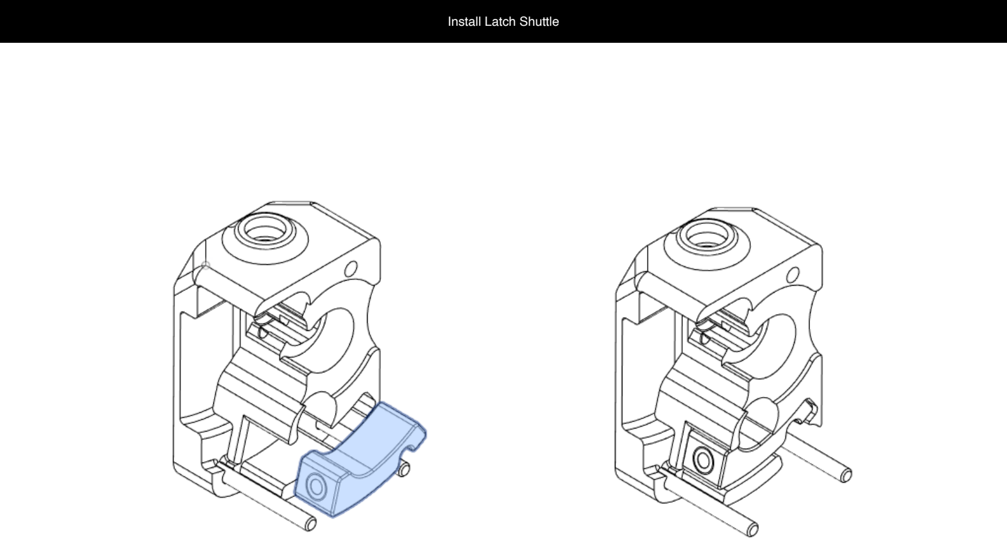
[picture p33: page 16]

## Install Latch

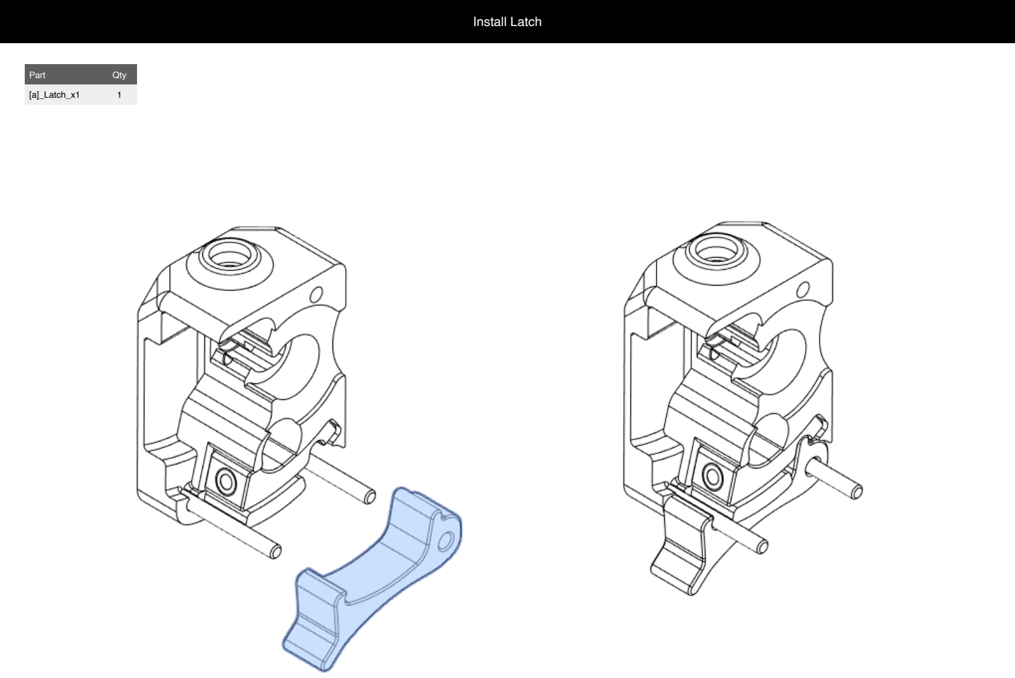
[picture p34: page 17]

Part | Qty
[a]_Latch_x1 | 1

## Marry the Halves

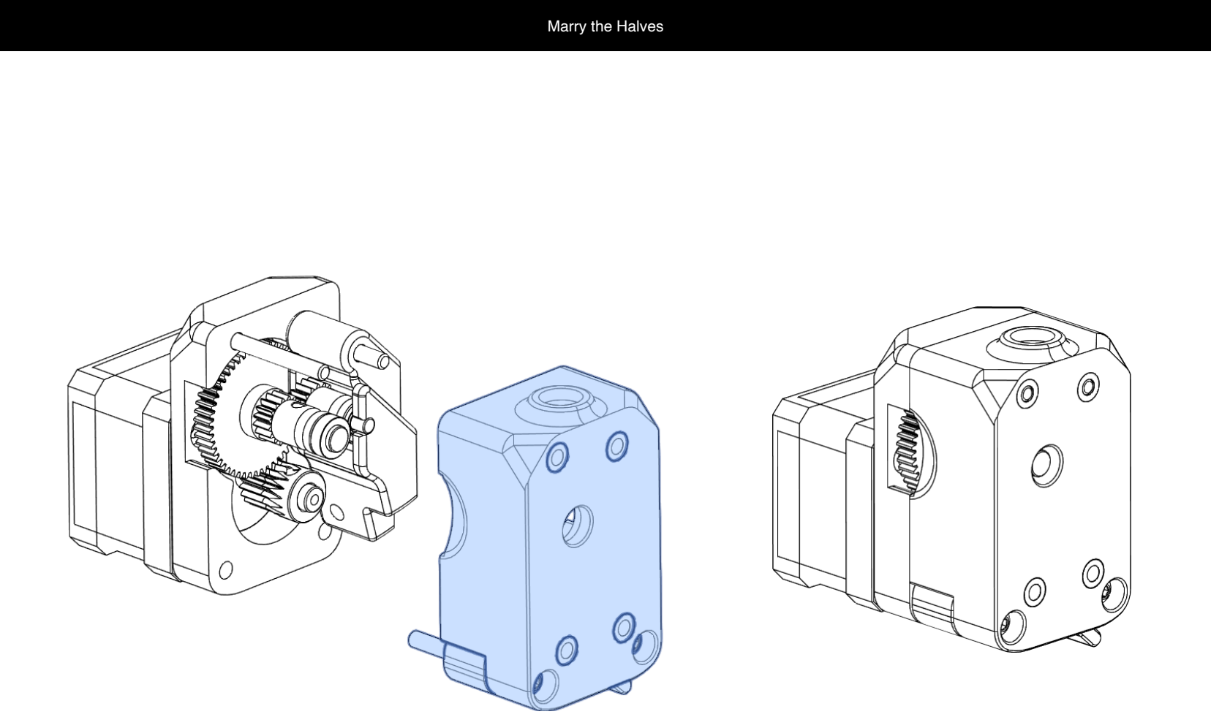
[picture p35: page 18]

## Final Touches

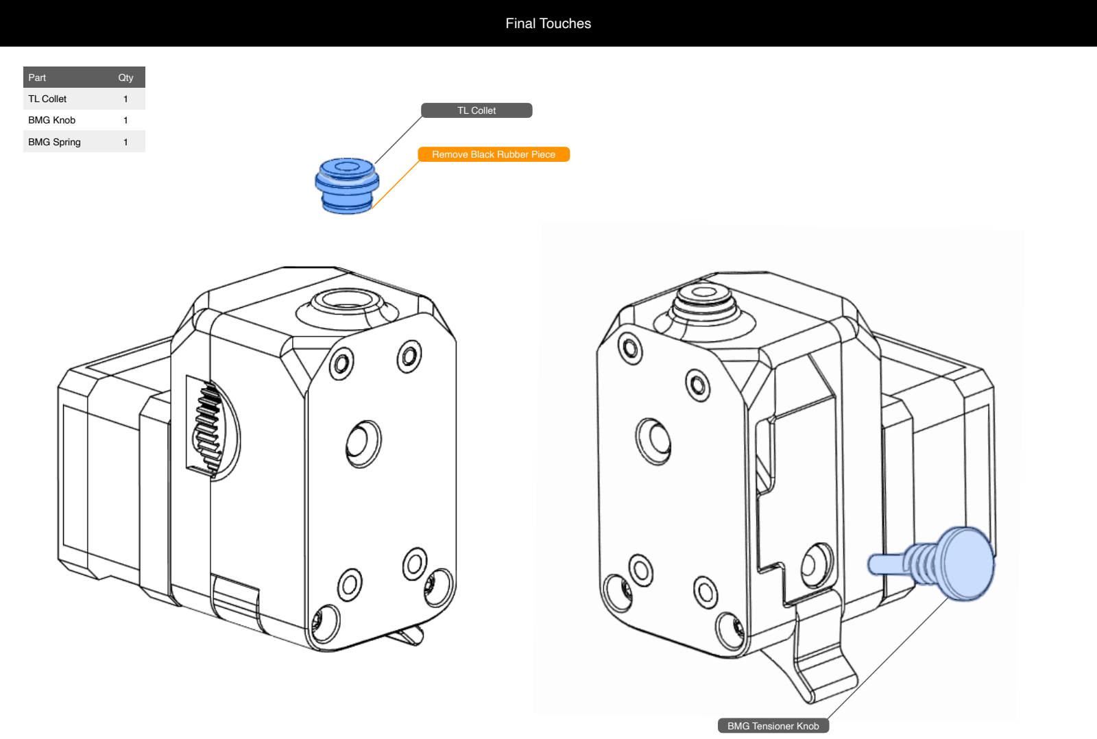
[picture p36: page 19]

TL Collet

BMG Tensioner Knob

Part | Qty
TL Collet | 1
BMG Knob | 1
BMG Spring | 1
Remove Black Rubber Piece

## YAY!

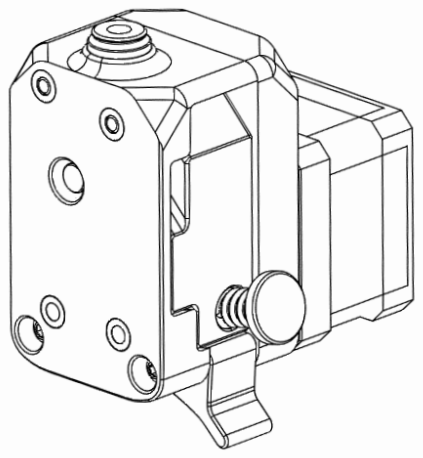
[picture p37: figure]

# Brought To You By; In No Particular Order

russiancatfood | Chron | etherwalker | Lolmodule | Strubinator | brick_sandwich
8Bit Poro | codeXmas | xanin | louielc | synlor | carnufex
aMpeX | daveidmx | fermion | Maglin | tameike | E.Lariviere
Andreq | Defib | fessyfoo | Medewsa | Thebrakshow | eddie
andylsun | dgcaste | fujimonster | Minasokoni | Timmit99 | insurgus
Arksine | DocJeeves | Fulg | Nemgrea | tinpec | johnprime
ArmyAg08 | doowrednu | Hackdoggo | pnewb | Trunkmonky | resam
bahahah | Drbpgh | Iakabos | pnokel | Ubernero | Stephan
Boff | dunar | Immutef | railgunner13f | _unregistered | wile.e.coyote
our husbands/wives/children/pets/significant others: for putting up with our shit, and dealing with our aliexpress

## packages

## Thanks!

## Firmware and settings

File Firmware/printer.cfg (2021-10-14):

# This file contains common pin mappings for the BIGTREETECH SKR
# MINI 2.0. To use this config, the firmware should be compiled for 
# the STM32F103 with a "28KiB bootloader". Also select "enable extra 
# low-level configuration options" and configure "GPIO pins to set 
# at micro-controller startup" to "!PA14".

# The "make flash" command does not work on the SKR mini. Instead,
# after running "make", copy the generated "out/klipper.bin" file to a
# file named "firmware.bin" on an SD card and then restart the SKR
# mini with that SD card.

# See the example.cfg file for a description of available parameters.

[mcu]
##	Obtain mcu value by "ls -l /dev/serial/by-id/" 
#serial: /dev/serial/by-id/usb-Klipper_stm32f103xe_REPLACE_WITH_YOUR_VALUE


[stepper_x]
step_pin: PB13
dir_pin: PB12           # check https://docs.vorondesign.com/build/startup/#v0 if moving in the wrong direction
enable_pin: !PB14
rotation_distance: 40
microsteps: 16
endstop_pin: PC0 
position_endstop: 120
position_max: 120
homing_speed: 20        # Increase after initial setup, Max 100
homing_retract_dist: 5
homing_positive_dir: true

[tmc2209 stepper_x]
uart_pin: PC11
tx_pin: PC10
uart_address: 0
interpolate: True
run_current: 0.5        # For V0.1 spec NEMA14 40Ncm
hold_current: 0.25
sense_resistor: 0.110
stealthchop_threshold: 500


[stepper_y]
step_pin: PB10
dir_pin: PB2            # check https://docs.vorondesign.com/build/startup/#v0 if moving in the wrong direction
enable_pin: !PB11
rotation_distance: 40
microsteps: 16
endstop_pin: PC1
position_endstop: 120
position_max: 120
homing_speed: 20        # Increase after initial setup, Max 100
homing_retract_dist: 5
homing_positive_dir: true

[tmc2209 stepper_y]
uart_pin: PC11
tx_pin: PC10
uart_address: 2
interpolate: True
run_current: 0.5        # For V0.1 spec NEMA14 40Ncm
hold_current: 0.25
sense_resistor: 0.110
stealthchop_threshold: 500


[stepper_z]
step_pin: PB0
dir_pin: !PC5           # Remove ! if moving opposite direction
enable_pin: !PB1
rotation_distance: 8    # For T8x8 integrated lead screw
microsteps: 16
endstop_pin: PC2
position_endstop: -0.10
position_max: 120
position_min: -1.5
homing_speed: 10        # Max 100
second_homing_speed: 3.0
homing_retract_dist: 3.0

[tmc2209 stepper_z]
uart_pin: PC11
tx_pin: PC10
uart_address: 1
interpolate: True
#run_current: 0.37       # For V0.1 spec NEMA17 LDO-42STH25-1004CL200E 1.0A  
#hold_current: 0.35
run_current: 0.2         # For V0.1 spec NEMA17 OMC 17LS13-0404E-200G 0.4A 
hold_current: 0.15
sense_resistor: 0.110
stealthchop_threshold: 500


[extruder]
step_pin: PB3
dir_pin: PB4            # Add ! if moving opposite direction
enable_pin: !PD2
full_steps_per_rotation: 200    # 1.8° motor LDO
#full_steps_per_rotation: 400    # 0.9° motor i.e OMC 14HR07-1004VRN
rotation_distance: 22.23        # See calibrating rotation_distance on extruders doc
gear_ratio: 50:10               # For Mini Afterburner
microsteps: 16
nozzle_diameter: 0.400
filament_diameter: 1.750
heater_pin: PC8
sensor_type: EPCOS 100K B57560G104F # Adjust for your hotend thermistor (see options below)
sensor_pin: PA0
control: pid            # Do PID calibration
pid_Kp: 28.182
pid_Ki: 1.978
pid_Kd: 100.397
min_temp: 0
max_temp: 270
min_extrude_temp: 170
max_extrude_only_distance: 780.0
max_extrude_cross_section: 0.8
pressure_advance: 0.0   # See tuning pressure advance doc
pressure_advance_smooth_time: 0.040

[tmc2209 extruder]
uart_pin: PC11
tx_pin: PC10
uart_address: 3
interpolate: True
run_current: 0.3	# for LDO 36STH17-1004AHG 
hold_current: 0.2	# for LDO 36STH17-1004AHG
#run_current: 0.5	# for OMC 14HR07-1004VRN rated at 1A
#hold_current: 0.3	# for OMC 14HR07-1004VRN rated at 1A
sense_resistor: 0.110
stealthchop_threshold: 500


[heater_bed]
heater_pin: PC9
sensor_type: NTC 100K beta 3950 # For Keenovo, verify yours
sensor_pin: PC3
smooth_time: 3.0
#max_power: 0.6         # Only need this for 100w pads
min_temp: 0
max_temp: 120
control: pid            # Do PID calibration
pid_kp: 68.453
pid_ki: 2.749
pid_kd: 426.122


[printer]
kinematics: corexy
max_velocity: 200
max_accel: 2000
max_z_velocity: 15
max_z_accel: 45
square_corner_velocity: 6.0


[heater_fan hotend_fan]
pin: PC7
max_power: 1.0
kick_start_time: 0.5
heater: extruder
heater_temp: 50.0
#fan_speed: 1.0         # You can't PWM the delta fan unless using blue wire


[fan]
pin: PC6
max_power: 1.0
kick_start_time: 0.5
#depending on your fan, you may need to increase or reduce this value
#if your fan will not start
off_below: 0.13
cycle_time: 0.010


[idle_timeout]
timeout: 1800


[safe_z_home]
home_xy_position: 120,120
speed: 50.0
z_hop: 5


# Tool to help adjust bed leveling screws. One may define a
# [bed_screws] config section to enable a BED_SCREWS_ADJUST g-code
# command.
[bed_screws]
screw1: 60,5
screw1_name: front screw
screw2: 5,115
screw2_name: back left
screw3: 115,115
screw3_name: back right


[gcode_macro PRINT_START]
#   Use PRINT_START for the slicer starting script - please customize for your slicer of choice
gcode:
    G28                            ; home all axes
    G1 Z20 F3000                   ; move nozzle away from bed
   
[gcode_macro PRINT_END]
#   Use PRINT_END for the slicer ending script - please customize for your slicer of choice
gcode:
    M400                           ; wait for buffer to clear
    G92 E0                         ; zero the extruder
    G1 E-4.0 F3600                 ; retract filament
    G91                            ; relative positioning

    #   Get Boundaries
    {% set max_x = printer.configfile.config["stepper_x"]["position_max"]|float %}
    {% set max_y = printer.configfile.config["stepper_y"]["position_max"]|float %}
    {% set max_z = printer.configfile.config["stepper_z"]["position_max"]|float %}

    #   Check end position to determine safe direction to move
    {% if printer.toolhead.position.x < (max_x - 20) %}
        {% set x_safe = 20.0 %}
    {% else %}
        {% set x_safe = -20.0 %}
    {% endif %}

    {% if printer.toolhead.position.y < (max_y - 20) %}
        {% set y_safe = 20.0 %}
    {% else %}
        {% set y_safe = -20.0 %}
    {% endif %}

    {% if printer.toolhead.position.z < (max_z - 2) %}
        {% set z_safe = 2.0 %}
    {% else %}
        {% set z_safe = max_z - printer.toolhead.position.z %}
    {% endif %}

    G0 Z{z_safe} F3600             ; move nozzle up
    G0 X{x_safe} Y{y_safe} F20000  ; move nozzle to remove stringing
    TURN_OFF_HEATERS
    M107                           ; turn off fan
    G90                            ; absolute positioning
    G0 X60 Y{max_y} F3600          ; park nozzle at rear
	
[gcode_macro LOAD_FILAMENT]
gcode:
   M83                            ; set extruder to relative
   G1 E30 F300                    ; load
   G1 E15 F150                    ; prime nozzle with filament
   M82                            ; set extruder to absolute
    
[gcode_macro UNLOAD_FILAMENT]
gcode:
   M83                            ; set extruder to relative
   G1 E10 F300                    ; extrude a little to soften tip
   G1 E-40 F1800                  ; retract some, but not too much or it will jam
   M82                            ; set extruder to absolute

# Sensor Types
#   "EPCOS 100K B57560G104F"
#   "ATC Semitec 104GT-2"
#   "NTC 100K beta 3950" (Keenovo Heater Pad)
#   "Honeywell 100K 135-104LAG-J01"
#   "NTC 100K MGB18-104F39050L32"
#   "AD595"
#   "PT100 INA826"
